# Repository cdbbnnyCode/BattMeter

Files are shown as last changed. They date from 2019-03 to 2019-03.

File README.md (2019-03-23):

## BattMeter  
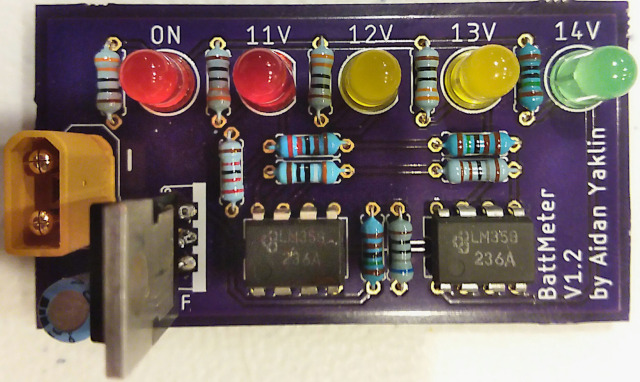
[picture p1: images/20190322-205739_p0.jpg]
PCB preview
   
BattMeter is a simple voltage meter for FTC batteries. The voltage ranges can be adjusted by changing the values of
r1, r2, r3, r4, and r5 (see [v1.2_voltages.txt](/v1.2_voltages.txt) for default resistor values).  
The board has an XT30 plug to connect REV batteries directly. If you have a different type of connector on your batteries, you can:
* Use an adapter plug
* Use a short length of wire and solder your connector onto that (recommended for crimped connectors like Tamiya and Anderson Powerpoles)
* Modify the board to fit your connector

### Usage
To edit these files, you need Autodesk Eagle. If you just want to fabricate a board, you should be able to find Gerber files under
the Releases page. You can find a list of the components you need under [bom.txt](/bom.txt).  
The PCB design and schematic are licensed under the [Creative Commons Attribution-ShareAlike 4.0 License](https://creativecommons.org/licenses/by-sa/4.0/).

### How it works
This meter uses four op-amp comparators to turn on the LEDs at specific input voltages.  
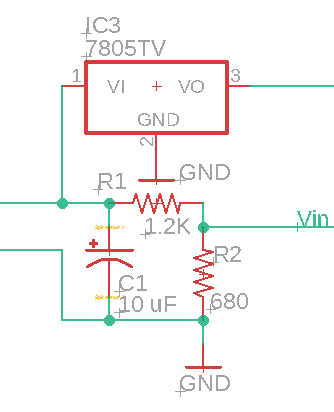
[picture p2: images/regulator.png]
Input and regulation
  
A voltage divider reduces the battery voltage to somewhere around 5V, and the regulator provides a (reasonably) fixed 5V reference.  
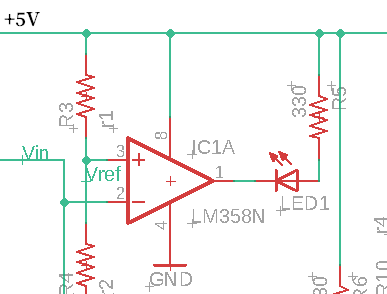
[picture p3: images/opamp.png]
A single comparator
  
The chain of resistors (r1, r2, r3, r4, and r5) drop the regulated voltage at specific steps, and the op-amps compare the scaled
battery voltage with this voltage. The logic is inverted--the input voltage is connected to the inverting input--because the LED
turns on when the op-amp's output is pulled to GND.

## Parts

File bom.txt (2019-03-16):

Here is a list of all of the components used on this board:
2x LM358 Dual Operational Amplifier
1x µA7805 5V Linear Regulator
1x 10µF Electrolytic Capacitor
7x Various 1/4W Resistors (see v1.2_voltages.txt for exact values)
5x 330Ω 1/4W Resistors (for the LEDs)
1x XT30U-M Connector (or whatever connector your batteries use)
5x 5mm LEDs (feel free to be creative with the colors!*)

* If you want even brightness, use 150Ω resistors on green and blue LEDs and 330Ω for LEDs in the red-yellow range.

Some ideas for improving this board:
* Add sticky foam to the back to avoid scratching up sufaces and/or short-circuiting when it is placed on a metal surface.
  Don't forget to add cutouts for the information on the back!
* 3D print a case for it--this might require modification of the connector arrangement and the LEDs.

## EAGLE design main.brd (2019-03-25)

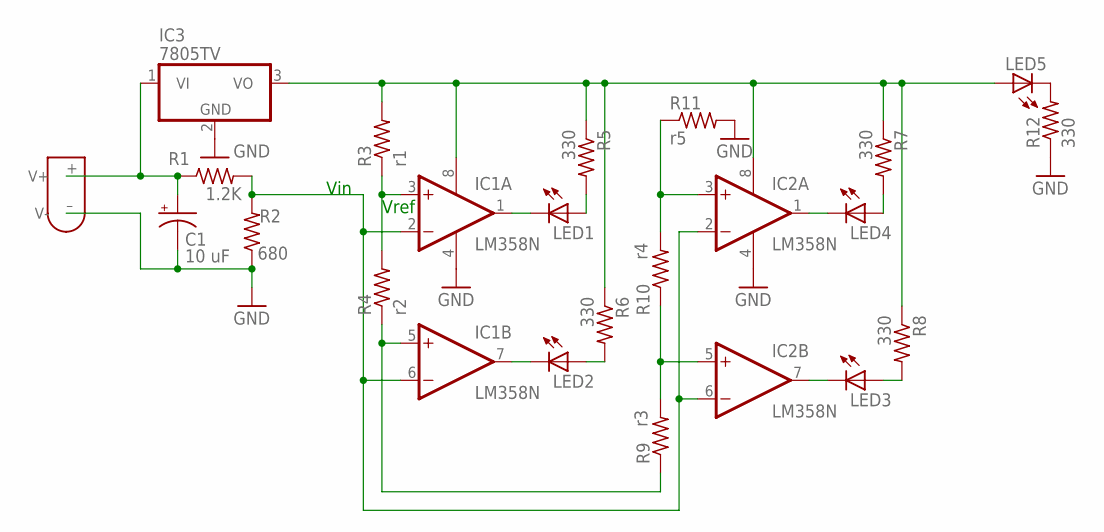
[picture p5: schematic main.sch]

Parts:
C1: 10 uF; E2-5
IC1, IC2: LM358N; DIL08
IC3: 7805TV; TO220V
LED1, LED2, LED3, LED4, LED5: LED5MM
R1: 1.2K; 0207/7
R2: 680; 0207/7
R3: r1; 0207/7
R4: r2; 0207/7
R5, R6, R7, R8, R12: 330; 0207/7
R9: r3; 0207/7
R10: r4; 0207/7
R11: r5; 0207/7
U$1: XT30

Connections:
GND: C1.-, IC1.4 (V-), IC2.4 (V-), IC3.2 (GND), R2.1, R11.2, R12.1, U$1.– (V-)
unnamed: IC1.3 (+IN), R3.1, R4.2
unnamed: C1.+, IC3.1 (VI), R1.1, U$1.+ (V+)
unnamed: IC1.8 (V+), IC2.8 (V+), IC3.3 (VO), LED5.A, R3.2, R5.1, R6.1, R7.1, R8.1
unnamed: IC1.5 (+IN), R4.1, R9.1
unnamed: IC1.1 (OUT), LED1.K (C)
unnamed: LED1.A, R5.2
unnamed: LED2.A, R6.2
unnamed: IC1.7 (OUT), LED2.K (C)
unnamed: IC2.1 (OUT), LED4.K (C)
unnamed: LED4.A, R7.2
unnamed: IC2.7 (OUT), LED3.K (C)
unnamed: LED3.A, R8.2
unnamed: IC1.2 (-IN), IC1.6 (-IN), IC2.2 (-IN), IC2.6 (-IN), R1.2, R2.2
unnamed: IC2.5 (+IN), R9.2, R10.1
unnamed: IC2.3 (+IN), R10.2, R11.1
unnamed: LED5.K (C), R12.2

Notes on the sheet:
Vref
Vin

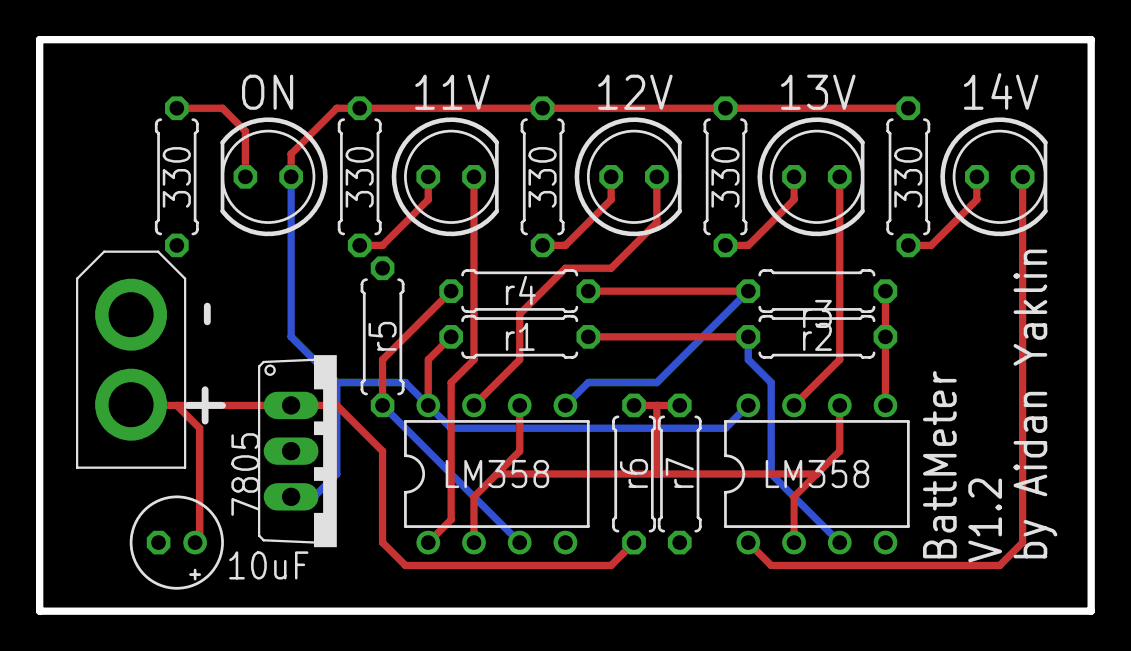
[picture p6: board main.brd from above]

Board: 2 copper layers, 58.4 x 31.8 mm, 23 parts (0 on the bottom side), 17 nets.

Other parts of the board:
U$2: LOGO

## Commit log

2019-03-13 Initial commit (V1.2)
    [main.brd, main.sch]
2019-03-16 Add BOM
2019-03-23 Add real board photo
    [main.brd, main.sch]
2019-03-25 Fix resistor values
    [main.brd]
